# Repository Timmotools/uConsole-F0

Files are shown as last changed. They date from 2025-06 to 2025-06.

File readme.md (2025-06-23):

uConsole to Flipper Zero module adapter PCB files. 

This is the first PCB I have designed in 20 years.

Recently I purchased the uConsole and thought, Wouldnt it be nice to have GPS, CC1101, NRF as modules rather than trying to manually install these. So here we are.

Rev 0.1 board doesnt have a revision number on the board and was the intial design I got made by PCBway. I made and ordered these before I had the uConsole in my hands. The boards I ordered were too thick so it allowed a second revision to be made to fix a few things.
Rev 0.1 only has basic parts. no speaker pads included.

Rev 0.2 will have the speaker pads. The USB holes will be relocated and the Flipper Zero plug will be flipped as I feel its upside down on Rev 0.2

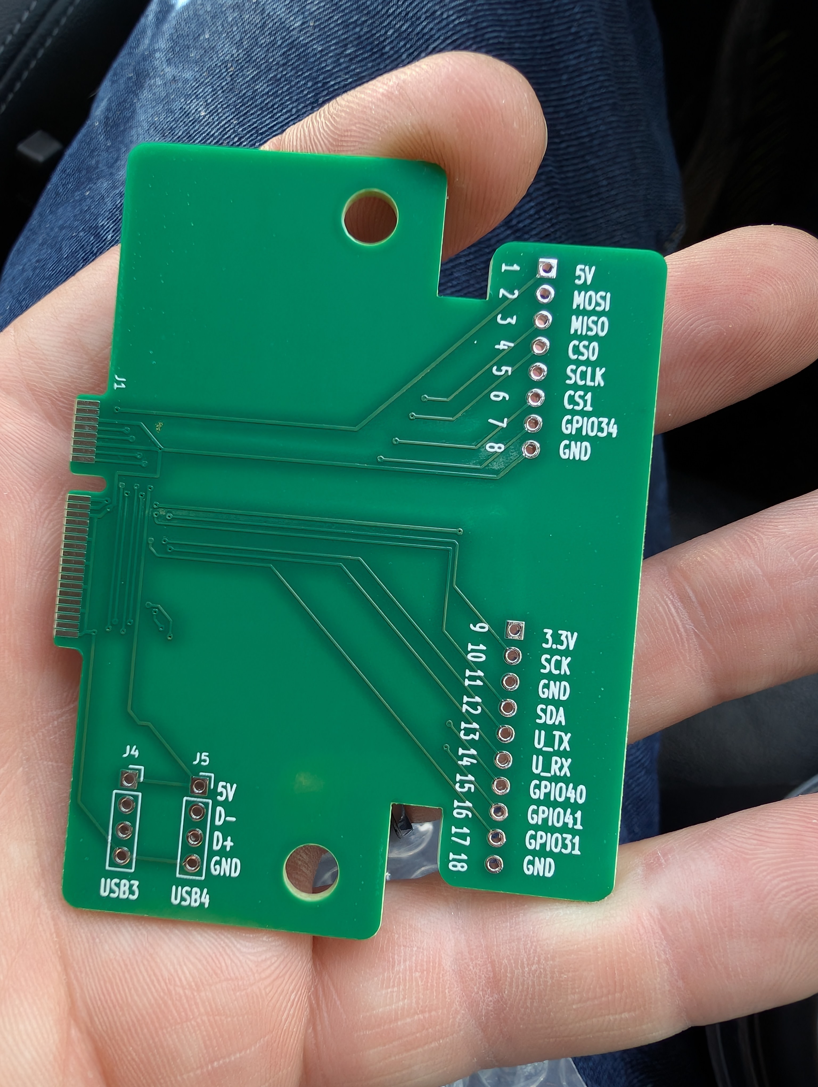
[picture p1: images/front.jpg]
front image

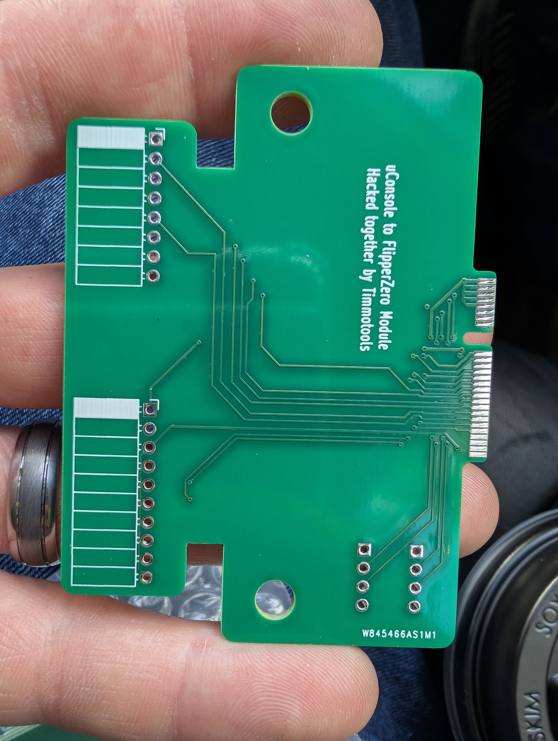
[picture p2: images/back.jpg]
back image

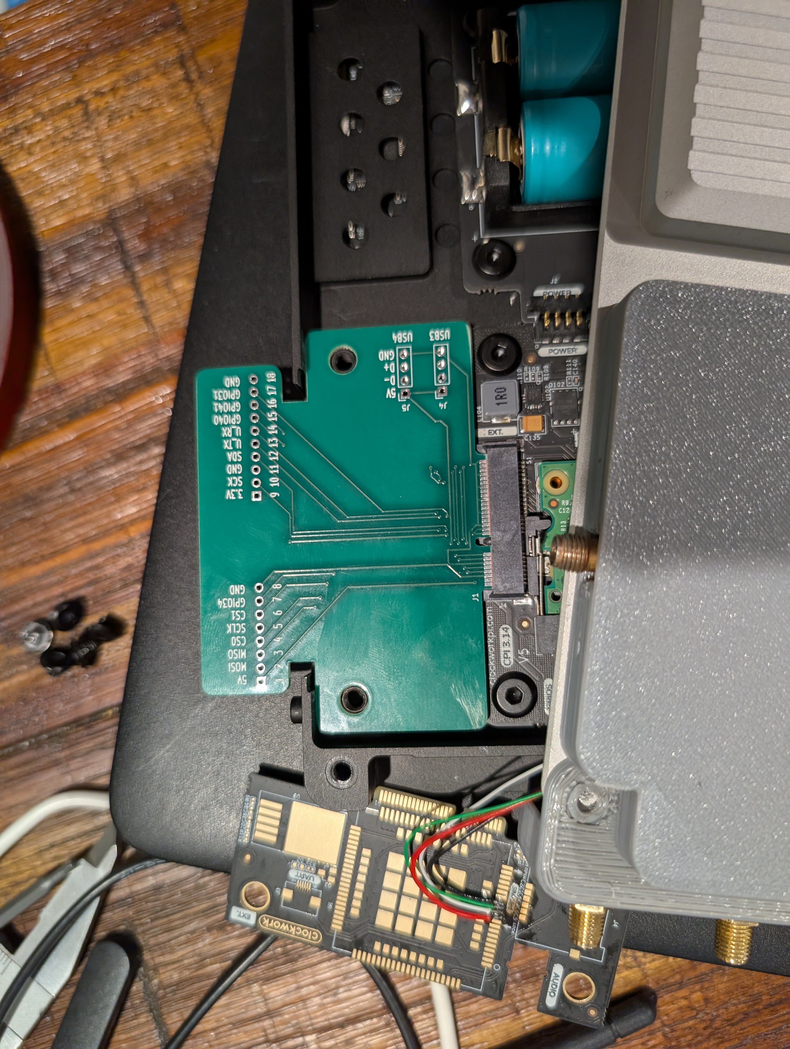
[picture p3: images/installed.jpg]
installed image


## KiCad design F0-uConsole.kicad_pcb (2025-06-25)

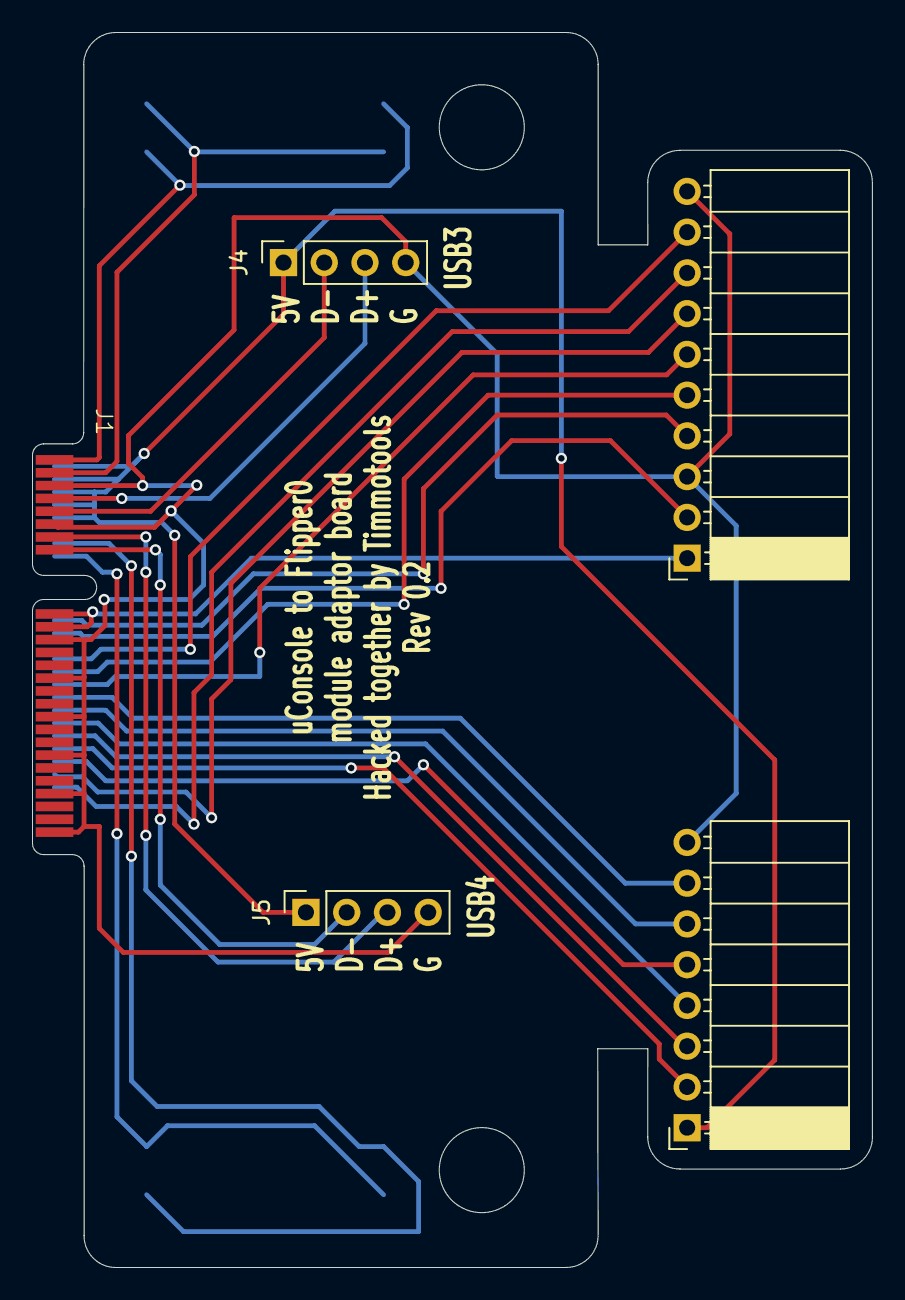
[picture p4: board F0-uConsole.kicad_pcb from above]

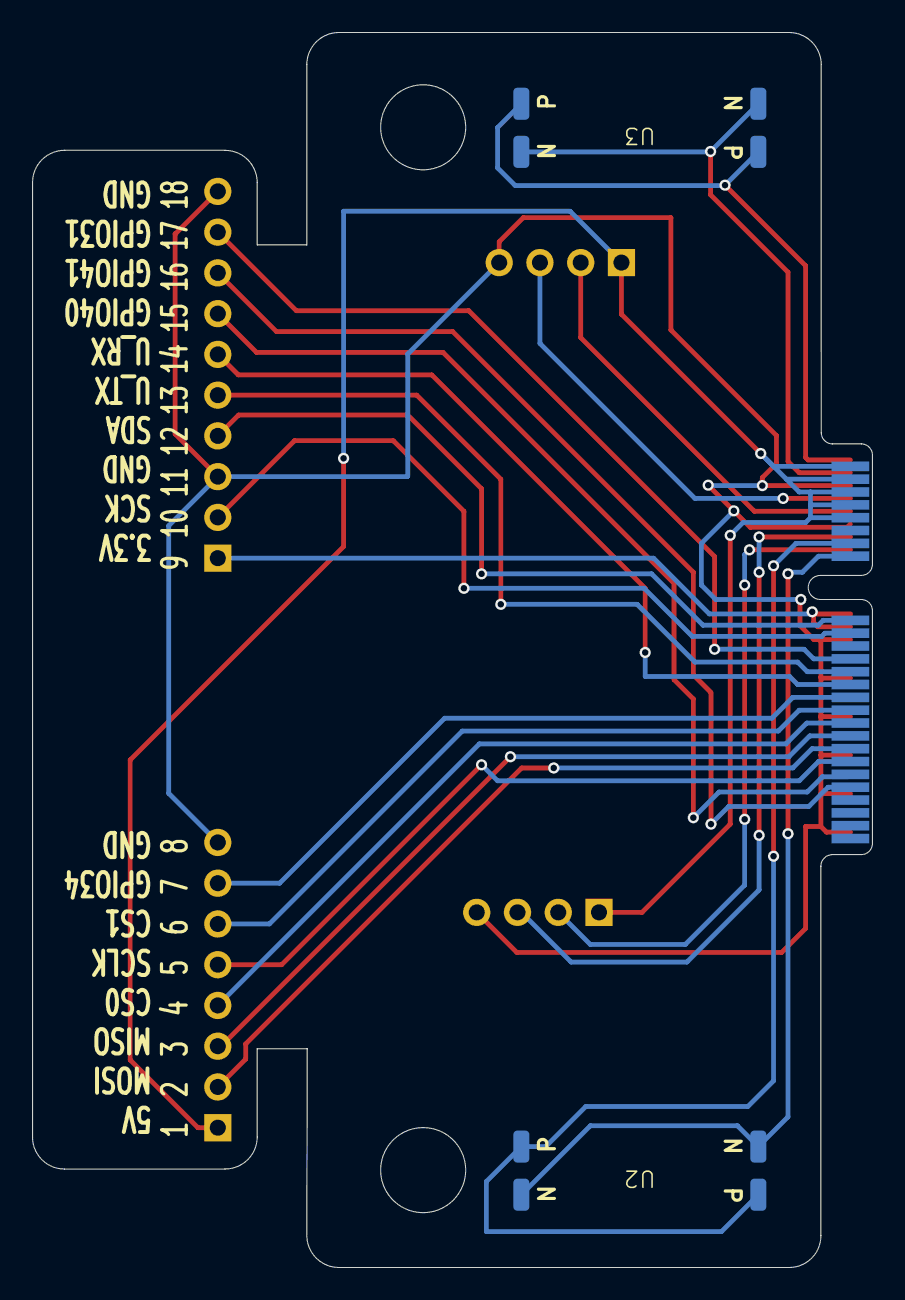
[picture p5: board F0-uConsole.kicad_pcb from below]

Board: 2 copper layers, 52.4 x 77.0 mm, 9 parts (2 on the bottom side), 24 nets.

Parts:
H1, H2: MountingHole; MountingHole_5.3mm_M5
J1: uConsoleEXT; ext_connector
J2: F0_1; PinSocket_1x08_P2.54mm_Horizontal
J3: F0_2; PinSocket_1x10_P2.54mm_Horizontal
J4: USB1; PinSocket_1x04_P2.54mm_Vertical
J5: USB2; PinSocket_1x04_P2.54mm_Vertical
U2, U3: Speaker; speaker pads

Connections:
+3.3V: J1.17 (3V3), J1.19 (3V3), J3.1
+5V: J1.2 (5V), J1.4 (5V), J1.6 (5V), J1.8 (5V), J1.10 (5V), J2.1, J4.1, J5.1
/SPK_LN: J1.3 (SPK_LN), U3.2 (N1), U3.4 (N2)
/SPK_LP: J1.1 (SPK_LP), U3.1, U3.3 (P2)
/SPK_RN: J1.16 (SPK_RN), U2.2 (N1), U2.4 (N2)
/SPK_RP: J1.14 (SPK_RP), U2.1, U2.3 (P2)
GND: J1.5 (GND), J1.11 (GND), J1.12 (GND), J1.21 (GND), J1.27 (GND), J1.33 (GND), J1.39 (GND), J1.45 (GND), J1.51 (GND), J2.8, J3.3, J3.10, J4.4, J5.4
GPIO34: J1.30 (GPIO34), J2.7
GPIO40: J1.42 (GPIO40), J3.7
GPIO41: J1.44 (GPIO41), J3.8
RTS0: J1.24 (GPIO31), J3.9
RXD0: J1.28 (GPIO33), J3.6
SCL: J1.20 (GPIO29), J3.2
SDA: J1.18 (GPIO28), J3.4
SPI_CE0: J1.34 (GPIO36), J2.4
SPI_CE1: J1.32 (GPIO35), J2.6
SPI_MISO: J1.36 (GPIO37), J2.3
SPI_MOSI: J1.38 (GPIO38), J2.2
SPI_SCLK: J1.40 (GPIO39), J2.5
TXD0: J1.26 (GPIO32), J3.5
USB3_DN: J1.9 (USB3_DM), J4.2
USB3_DP: J1.7 (USB3_DP), J4.3
USB4_DN: J1.15 (USB4_DM), J5.2
USB4_DP: J1.13 (USB4_DP), J5.3

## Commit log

2025-06-23 upload of Rev 0.1 board.
    [F0-uConsole-B_Cu.gbr, F0-uConsole-B_Mask.gbr, F0-uConsole-B_Paste.gbr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]
2025-06-23 add images of Rev 0.1 board
2025-06-25 Upload Rev0.2 board
    change notes:
    added speaker terminals
    flipped the flipper connector so the module face would be facing the user. basically this meant a full redesign.
    shortened the card slightly.
    [F0-uConsole-B_Cu.gbr, F0-uConsole-B_Mask.gbr, F0-uConsole-B_Paste.gbr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]
2025-06-25 upload Rev0.2
    forgot the revision on the silkscreen.
    [F0-uConsole-B_Cu.gbr, F0-uConsole-B_Mask.gbr, F0-uConsole-B_Paste.gbr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]
